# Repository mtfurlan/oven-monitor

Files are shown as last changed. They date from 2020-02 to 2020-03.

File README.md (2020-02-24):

# Oven Monitor
d1 mini + oled + k type thermocouple to track oven temperature

## Features
* Displays oven temperature if over 70C
* Reports temperature over mqtt every 60 seconds or on a 5 degree change

## Code features
* rolling average for ADC
* The rest is thermostat code

## BOM
* adafruit AD8495 Breakout: https://www.adafruit.com/product/1778
* K type thermocouple
* d1 mini
* oled display i2c SSD1306 128X64

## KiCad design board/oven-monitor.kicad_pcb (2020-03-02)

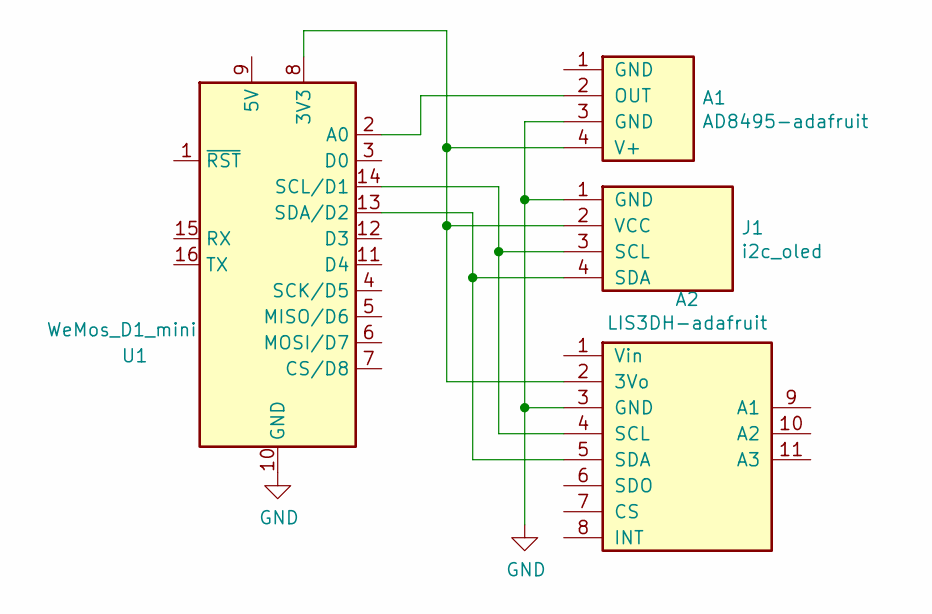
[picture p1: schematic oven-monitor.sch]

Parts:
A1: AD8495-adafruit
A2: LIS3DH-adafruit
J1: i2c_oled
U1: WeMos_D1_mini; WEMOS_D1_mini_light

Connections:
GND: A1.3 (GND), A2.3 (GND), J1.1 (GND), U1.10 (GND)
unnamed: A1.2 (OUT), U1.2 (A0)
unnamed: A1.4 (V+), A2.2 (3Vo), J1.2 (VCC), U1.8 (3V3)
unnamed: A2.4 (SCL), J1.3 (SCL), U1.14 (SCL/D1)
unnamed: A2.5 (SDA), J1.4 (SDA), U1.13 (SDA/D2)

Board: 2 copper layers, 4 parts (1 on the bottom side), 5 nets, no tracks yet.

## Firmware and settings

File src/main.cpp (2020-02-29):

/**
 * This works mostly by global magics.
 * We have an array of ADC readings, an index, and a running sum.
 * This allows window averaging.
 *
 * There is also a global float temp, reportedTemp, and displayedTemp.
 * temp is the last known temperature, the other two are for figuring out when
 * to update the display or MQTT.
 *
 * Single tap wakes display for DISPLAY_ON_LENGTH
 * Double tap changes units
 *
 * Variables you might want to fuck with:
 *  STATUS_INTERVAL: minimum mqtt update frequency (ms)
 *  TEMP_REPORT_SIZE: tempreature change upon which to update MQTT (c).
 *  OVEN_COOL_THRESH: don't turn on the display below this many degrees C
 *  MQTT_ENABLED: comment out if you don't want mqtt
 **/
//comment out if not using MQTT
//#define MQTT_ENABLED

//Maximum amount of time between MQTT updates (ms)
#define STATUS_INTERVAL 60000UL
//how big a temperature swing to report to MQTT
#define TEMP_REPORT_SIZE 5

//Don't display if temp is below this
#define OVEN_COOL_THRESH 42

//how big the thermocouple averaging window is
#define ADC_NUM_READINGS 50

//how fast to poll the ADC/IMU
#define ADC_INTERVAL 10
#define IMU_INTERVAL 100

//Do you want to default to bad units for display
#define USE_BAD_UNITS false

// how long the display stays on after it doesn't need to be
#define DISPLAY_ON_LENGTH 10000UL

#include "oven-monitor.h"
#include "pins.h"

#include <Arduino.h>
#include <U8g2lib.h>
#include <Wire.h>
#include <Adafruit_LIS3DH.h>
#include <Adafruit_Sensor.h>

#ifdef MQTT_ENABLED
#include <mqtt-wrapper.h>

uint32_t nextStatus = 0UL;
float reportedTemp = 0;
bool mqttDirty;
struct mqtt_wrapper_options mqtt_options;
enum ConnState connState;
char topicBuf[1024];
#endif

uint32_t nextADCRead = 0UL;
uint32_t nextIMURead = 0UL;

//For the ADC, we want some smoothing
//So we average the past ADC_NUM_READINGS readings
//adc_init says if we've read enough readings yet
int adc_readings[ADC_NUM_READINGS];
int adc_sum = 0;
int adc_index = 0;
bool adc_init = false;

float temp = 0;
float displayedTemp = 0;

bool convertDisplayUnits = USE_BAD_UNITS;
bool displayDirty;
bool displayOn;
uint32_t displayTimeout = 0;

U8G2_SSD1306_128X64_NONAME_F_HW_I2C u8g2(U8G2_R0, /* reset=*/ U8X8_PIN_NONE, /* clock=*/ SCL_PIN, /* data=*/ SDA_PIN);
Adafruit_LIS3DH lis = Adafruit_LIS3DH();

char buf[1024];

void display() {
    displayedTemp = temp;
    //If we're too cold, and the display is timed out, turn the display off
    if(temp < OVEN_COOL_THRESH  && (long)( millis() - displayTimeout ) >= 0) {
        u8g2.setPowerSave(1);
        displayOn = false;
        return;
    }
    //else, display is on
    displayOn = true;
    if(temp >= OVEN_COOL_THRESH) {
        displayTimeout = millis() + DISPLAY_ON_LENGTH;
    }

    u8g2.clearBuffer();
    u8g2.setFont(u8g2_font_inr38_mf);

    //put temp in buf
    if(convertDisplayUnits) {
        sprintf(buf, "%.0fF", temp*9/5 + 32);
    } else {
        sprintf(buf, "%.0fC", temp);
    }

    //display buf
    u8g2.drawStr(0, 50, buf);


#ifdef MQTT_ENABLED
    //show mqtt connected status
    u8g2.setFont(u8g2_font_unifont_t_symbols);
    // https://github.com/olikraus/u8g2/wiki/fntgrpunifont
    // bottom of page
    switch(connState) {
        case F_MQTT_CONNECTED:
            u8g2.drawGlyph(119, 10, 0x25C6);	/* dec 9670/hex 25C6 solid diamond */
            break;
        case F_MQTT_DISCONNECTED:
            u8g2.drawGlyph(119, 10, 0x25C8);	/* dec 9672/hex 25C8 dot inside diamond */
            break;
        case WIFI_DISCONNECTED:
            u8g2.drawGlyph(119, 10, 0x25C7);	/* dec 9671/hex 25C7 empty diamond */
            break;
    }
#endif
    u8g2.sendBuffer();
    u8g2.setPowerSave(0);
}

//read ADC into adc_readings, pudate adc_sum/adc_init
void readADC() {
    adc_sum -= adc_readings[adc_index];
    adc_readings[adc_index] = analogRead(THERMOCOUPLE_PIN);
    adc_sum += adc_readings[adc_index];
    adc_index = (adc_index+1) % ADC_NUM_READINGS;

    if(!adc_init && adc_index == 0) {
        //we've wrapped back to 0
        adc_init = true;
    }
}

//calculate temp from adc_sum; update temp and display/mqtt dirty
void calculateTemp() {
#define AREF 3.2
#define ADC_RESOLUTION 10
    if(!adc_init) {
        return;
    }

    float voltage = ((float)adc_sum)/ADC_NUM_READINGS * (AREF / (pow(2, ADC_RESOLUTION)-1));
    temp = (voltage - 1.25) / 0.005;

    //sprintf(buf, "t: %f, v: %f, raw: %f\n", temp, voltage, ((float)adc_sum)/ADC_NUM_READINGS);
    //Serial.print(buf);

#ifdef MQTT_ENABLED
    if(abs(temp-reportedTemp) > TEMP_REPORT_SIZE) {
        mqttDirty = true;
    }
#endif

    if(abs(temp-displayedTemp) > 0) {
        displayDirty = true;
    }
}

#ifdef MQTT_ENABLED
void reportTelemetry(PubSubClient *client) {
    sprintf(topicBuf, "tele/%s/temp", TOPIC);
    //sprintf(buf, "%f", temp);
    dtostrf(temp, 0, 0, buf);
    client->publish(topicBuf, buf);

    reportedTemp = temp;
}

void callback(char* topic, byte* payload, unsigned int length, PubSubClient *client) {
    sprintf(topicBuf, "stat/%s/what", TOPIC);
    client->publish(topicBuf, "bad command");
}

void connectionEvent(PubSubClient* client, enum ConnState state, int reason) {
    connState = state;
    //Skipping displayDirty because sometimes this is called with no looping
    //like for wifi connect and then mqtt connect
    display();
}

void connectSuccess(PubSubClient* client, char* ip) {
    //Are subscribed to cmnd/fullTopic/+
}

void connectedLoop(PubSubClient* client) {
    if(mqttDirty || (long)( millis() - nextStatus ) >= 0) {
        nextStatus = millis() + STATUS_INTERVAL;
        mqttDirty = false;
        reportTelemetry(client);
    }
}
#endif

void setup() {
    Serial.begin(115200);
    Serial.println("Starting oven monitor");


    // --- Display ---
    u8g2.setI2CAddress(0x78);
    u8g2.begin();
    u8g2.clearBuffer();
    u8g2.sendBuffer();

    //accelelerometer
    if (! lis.begin(0x18)) {     // change this to 0x19 for alternative i2c address
        Serial.println("Couldnt start accelerometer");
    }
    // https://cdn-shop.adafruit.com/datasheets/LIS3DHappnote.pdf


    lis.setRange(LIS3DH_RANGE_2_G); // 2, 4, 8 or 16 G!

    // threshhold: click senitivity: strongly depend on the range!
    // for 16G, try 5-10, for 8G, try 10-20. for 4G try 20-40. for 2G try 40-80

    // c, thresh, timelimit(10), timelatency(20), timewindow(255)
    // adafruit defaults in ()
    lis.setClick(2, 80, 10, 20, 50);

#ifdef MQTT_ENABLED
    // --- MQTT ---
    mqtt_options.connectedLoop = connectedLoop;
    mqtt_options.callback = callback;
    mqtt_options.connectSuccess = connectSuccess;
    mqtt_options.connectionEvent = connectionEvent;
    mqtt_options.ssid = WIFI_SSID;
    mqtt_options.password = WIFI_PASSWORD;
    mqtt_options.mqtt_server = MQTT_SERVER;
    mqtt_options.mqtt_port = MQTT_PORT;
    mqtt_options.host_name = NAME;
    mqtt_options.fullTopic = TOPIC;
    mqtt_options.debug_print = true;
    setup_mqtt(&mqtt_options);
#endif

    //empty adc reading array
    for(int i = 0; i < ADC_NUM_READINGS; ++i) {
        adc_readings[i] = 0;
    }
}


void loop() {
#ifdef MQTT_ENABLED
    loop_mqtt();
#endif
    //read ADC
    if( (long)( millis() - nextADCRead ) >= 0) {
        nextADCRead = millis() + ADC_INTERVAL;
        readADC();
        calculateTemp();
    }
    //check for taps
    if( (long)( millis() - nextIMURead ) >= 0) {
        nextIMURead = millis() + IMU_INTERVAL;
        uint8_t click = lis.getClick();
        if (click & 0x30) {
            //either click
            displayTimeout = millis() + DISPLAY_ON_LENGTH;
            displayDirty = true;
        }
        if (click & 0x10) {
            Serial.println("single click");
        }
        if (click & 0x20) {
            Serial.println("double click");
            convertDisplayUnits = !convertDisplayUnits;
        }
    }

    //if display timed out, update display
    if((long)( millis() - displayTimeout ) >= 0) {
        displayDirty = true;
    }

    //mqtt loop called before this
    if(displayDirty) {
        displayDirty = false;
        display();
    }
}
